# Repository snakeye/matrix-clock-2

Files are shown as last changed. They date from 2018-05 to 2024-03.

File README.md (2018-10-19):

# LED Matrix Clock

These clock are build using ESP8266 module ESP-12. Arduino IDE was used for the firmware development and upload.

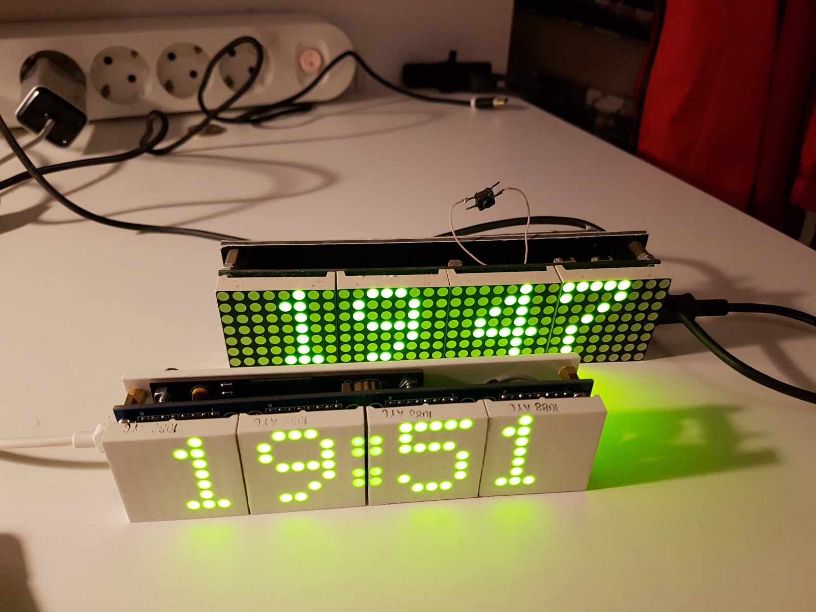
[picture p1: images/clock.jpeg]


## Features

* Built on ESP8266 WiFi module
* Time updates via NTP protocol
* Automatic time zone support
* Timekeeping without Internet connection (DS3231 chip)
* Brightness auto adjust

## Dependencies

* WiFi Manager - [https://github.com/tzapu/WiFiManager](https://github.com/tzapu/WiFiManager)
* Time library - [https://github.com/PaulStoffregen/Time](https://github.com/PaulStoffregen/Time)
* Time zone library - [https://github.com/JChristensen/Timezone](https://github.com/JChristensen/Timezone)
* NTP Client - [https://github.com/gmag11/NtpClient](https://github.com/gmag11/NtpClient)
* RTC library - [https://github.com/Makuna/Rtc](https://github.com/Makuna/Rtc)
* MAX7219 library - [https://github.com/snakeye/MAX7219_Display](https://github.com/snakeye/MAX7219_Display)

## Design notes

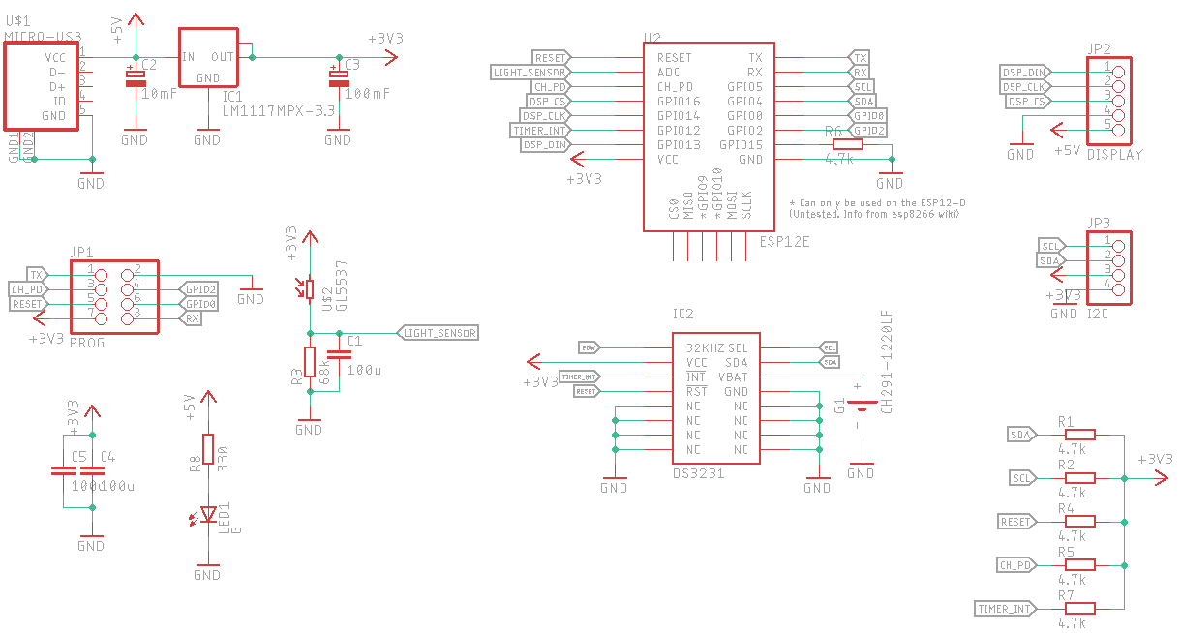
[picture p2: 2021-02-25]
images/schematics v1.png

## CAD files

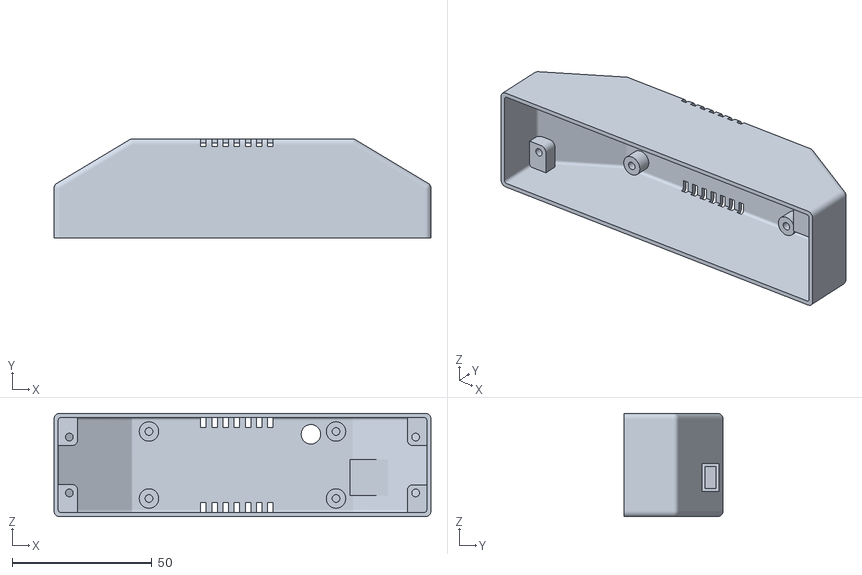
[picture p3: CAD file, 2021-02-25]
hardware/Enclosure.stl
135.0 x 35.5 x 37.0

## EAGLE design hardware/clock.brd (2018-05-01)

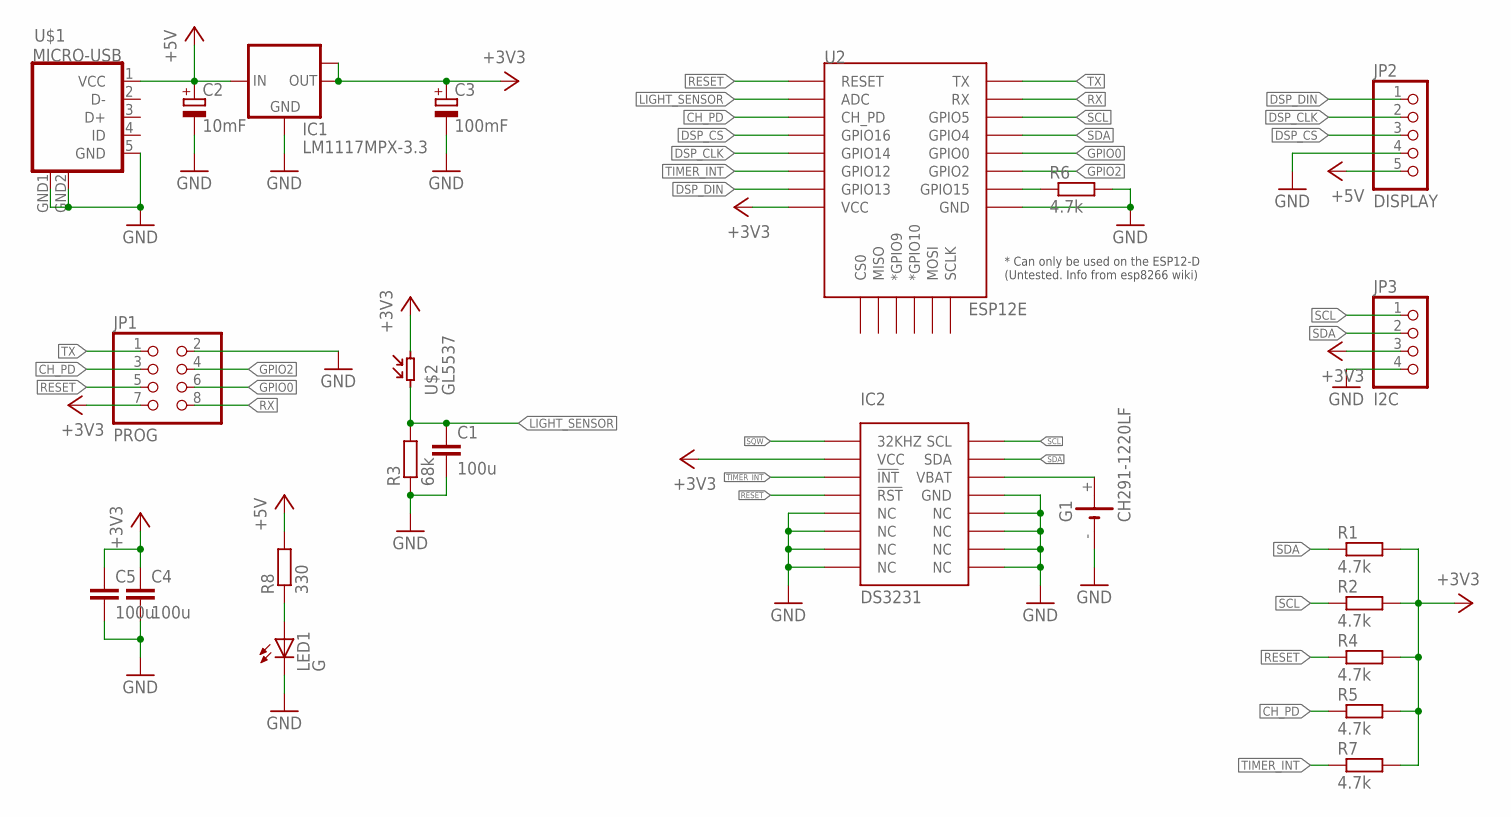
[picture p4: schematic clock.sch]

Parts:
C1, C4, C5: 100u; C0805
C2: 10mF; A/3216-18W
C3: 100mF; A/3216-18W
G1: CH291-1220LF
IC1: LM1117MPX-3.3; SOT223
IC2: DS3231; SOIC-16W
JP1: PROG; 2X04
JP2: DISPLAY; 1X05
JP3: I2C; 1X04
LED1: G; CHIPLED_0805
R1, R2, R4, R5, R6, R7: 4.7k; M0805
R3: 68k; M0805
R8: 330; M0805
U2: ESP12E; ESP12E-SMD
U$1: MICRO-USB
U$2: GL5537; GL55

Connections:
+3V3: C3.+, C4.1, C5.1, IC1.2 (OUT), IC1.TAB (OUT1), IC2.2 (VCC), JP1.7, JP3.3, R1.2, R2.2, R4.2, R5.2, R7.2, U2.VCC, U$2.P$2
+5V: C2.+, IC1.3 (IN), JP2.5, R8.2, U$1.1 (VCC)
CH_PD: JP1.3, R5.1, U2.CH_PD
DSP_CLK: JP2.2, U2.GPIO14
DSP_CS: JP2.3, U2.GPIO16
DSP_DIN: JP2.1, U2.GPIO13
GND: C1.2, C2.-, C3.-, C4.2, C5.2, G1.-, IC1.1 (GND), IC2.5 (NC), IC2.6 (NC), IC2.7 (NC), IC2.8 (NC), IC2.9 (NC), IC2.10 (NC), IC2.11 (NC), IC2.12 (NC), IC2.13 (GND), JP1.2, JP2.4, JP3.4, LED1.C, R3.1, R6.2, U2.GND, U$1.5 (GND), U$1.GND1 (GND), U$1.GND2 (GND)
GPIO0: JP1.6, U2.GPIO0
GPIO2: JP1.4, U2.GPIO2
GPIO15: R6.1, U2.GPIO15
LIGHT_SENSOR: C1.1, R3.2, U2.ADC, U$2.P$1
unnamed: LED1.A, R8.1
unnamed: G1.+, IC2.14 (VBAT)
RESET: IC2.4 (!RST), JP1.5, R4.1, U2.RESET
RX: JP1.8, U2.RXD0 (RX)
SCL: IC2.16 (SCL), JP3.1, R2.1, U2.GPIO5
SDA: IC2.15 (SDA), JP3.2, R1.1, U2.GPIO4
SQW: IC2.1 (32KHZ)
TIMER_INT: IC2.3 (!INT), R7.1, U2.GPIO12
TX: JP1.1, U2.TXD0 (TX)

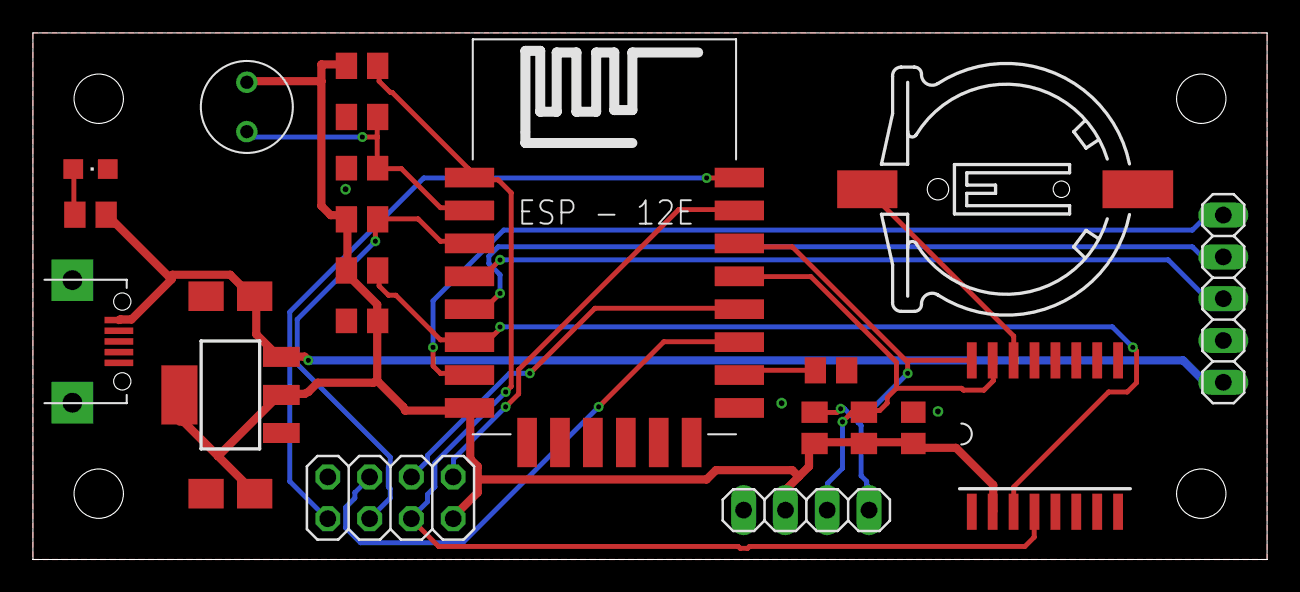
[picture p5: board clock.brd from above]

Board: 2 copper layers, 75.0 x 32.0 mm, 23 parts (0 on the bottom side), 19 nets.

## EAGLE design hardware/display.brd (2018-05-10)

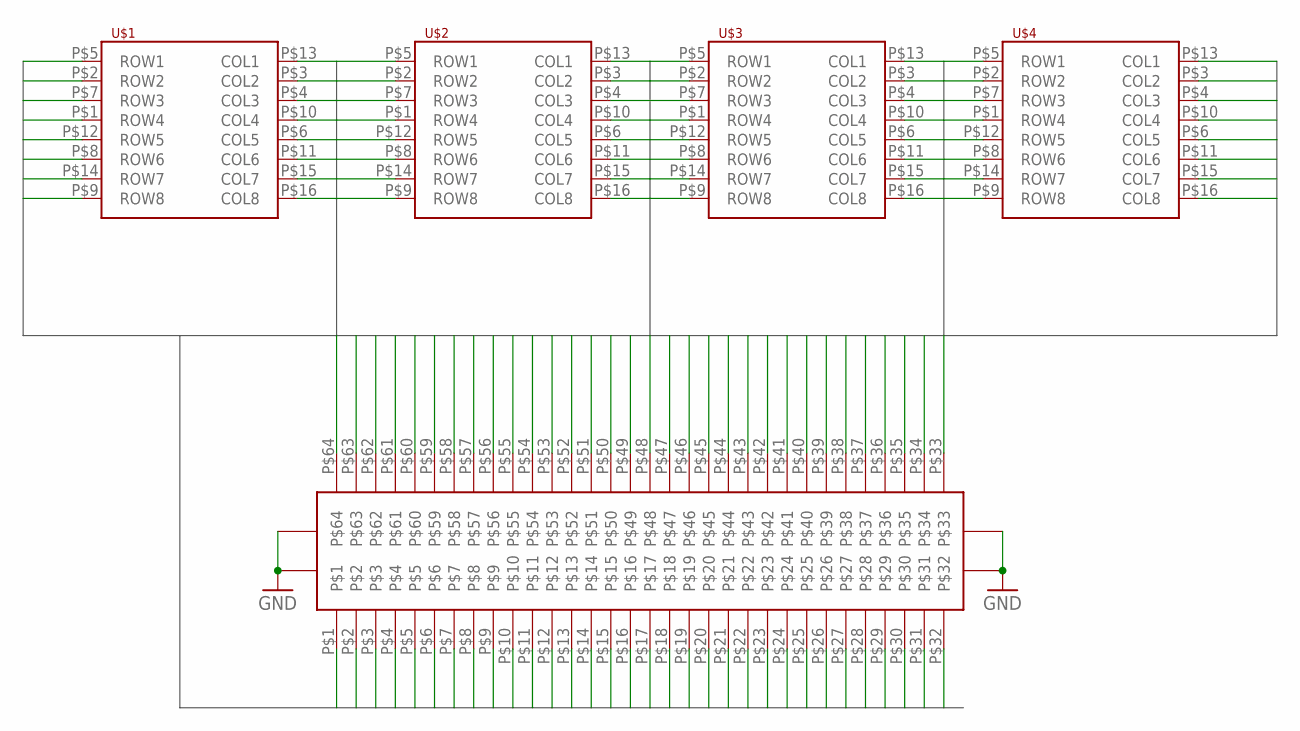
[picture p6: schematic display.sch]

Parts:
U$1, U$2, U$3, U$4: LED_8X8_MATRIX07088BH; MATRIX_8X8_20MM
U$5: ANGLE_BOARD_CONNECTORONE_SIDED; ONE_SIDED

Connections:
GND: U$5.GND@1 (GND), U$5.GND@2 (GND), U$5.GND@3 (GND), U$5.GND@4 (GND)
M1C1: U$1.P$13 (COL1), U$5.P$64
M1C2: U$1.P$3 (COL2), U$5.P$63
M1C3: U$1.P$4 (COL3), U$5.P$62
M1C4: U$1.P$10 (COL4), U$5.P$61
M1C5: U$1.P$6 (COL5), U$5.P$60
M1C6: U$1.P$11 (COL6), U$5.P$59
M1C7: U$1.P$15 (COL7), U$5.P$58
M1C8: U$1.P$16 (COL8), U$5.P$57
M1R1: U$1.P$5 (ROW1), U$5.P$1
M1R2: U$1.P$2 (ROW2), U$5.P$2
M1R3: U$1.P$7 (ROW3), U$5.P$3
M1R4: U$1.P$1 (ROW4), U$5.P$4
M1R5: U$1.P$12 (ROW5), U$5.P$5
M1R6: U$1.P$8 (ROW6), U$5.P$6
M1R7: U$1.P$14 (ROW7), U$5.P$7
M1R8: U$1.P$9 (ROW8), U$5.P$8
M2C1: U$2.P$13 (COL1), U$5.P$56
M2C2: U$2.P$3 (COL2), U$5.P$55
M2C3: U$2.P$4 (COL3), U$5.P$54
M2C4: U$2.P$10 (COL4), U$5.P$53
M2C5: U$2.P$6 (COL5), U$5.P$52
M2C6: U$2.P$11 (COL6), U$5.P$51
M2C7: U$2.P$15 (COL7), U$5.P$50
M2C8: U$2.P$16 (COL8), U$5.P$49
M2R1: U$2.P$5 (ROW1), U$5.P$9
M2R2: U$2.P$2 (ROW2), U$5.P$10
M2R3: U$2.P$7 (ROW3), U$5.P$11
M2R4: U$2.P$1 (ROW4), U$5.P$12
M2R5: U$2.P$12 (ROW5), U$5.P$13
M2R6: U$2.P$8 (ROW6), U$5.P$14
M2R7: U$2.P$14 (ROW7), U$5.P$15
M2R8: U$2.P$9 (ROW8), U$5.P$16
M3C1: U$3.P$13 (COL1), U$5.P$48
M3C2: U$3.P$3 (COL2), U$5.P$47
M3C3: U$3.P$4 (COL3), U$5.P$46
M3C4: U$3.P$10 (COL4), U$5.P$45
M3C5: U$3.P$6 (COL5), U$5.P$44
M3C6: U$3.P$11 (COL6), U$5.P$43
M3C7: U$3.P$15 (COL7), U$5.P$42
M3C8: U$3.P$16 (COL8), U$5.P$41
M3R1: U$3.P$5 (ROW1), U$5.P$17
M3R2: U$3.P$2 (ROW2), U$5.P$18
M3R3: U$3.P$7 (ROW3), U$5.P$19
M3R4: U$3.P$1 (ROW4), U$5.P$20
M3R5: U$3.P$12 (ROW5), U$5.P$21
M3R6: U$3.P$8 (ROW6), U$5.P$22
M3R7: U$3.P$14 (ROW7), U$5.P$23
M3R8: U$3.P$9 (ROW8), U$5.P$24
M4C1: U$4.P$13 (COL1), U$5.P$40
M4C2: U$4.P$3 (COL2), U$5.P$39
M4C3: U$4.P$4 (COL3), U$5.P$38
M4C4: U$4.P$10 (COL4), U$5.P$37
M4C5: U$4.P$6 (COL5), U$5.P$36
M4C6: U$4.P$11 (COL6), U$5.P$35
M4C7: U$4.P$15 (COL7), U$5.P$34
M4C8: U$4.P$16 (COL8), U$5.P$33
M4R1: U$4.P$5 (ROW1), U$5.P$25
M4R2: U$4.P$2 (ROW2), U$5.P$26
M4R3: U$4.P$7 (ROW3), U$5.P$27
M4R4: U$4.P$1 (ROW4), U$5.P$28
M4R5: U$4.P$12 (ROW5), U$5.P$29
M4R6: U$4.P$8 (ROW6), U$5.P$30
M4R7: U$4.P$14 (ROW7), U$5.P$31
M4R8: U$4.P$9 (ROW8), U$5.P$32

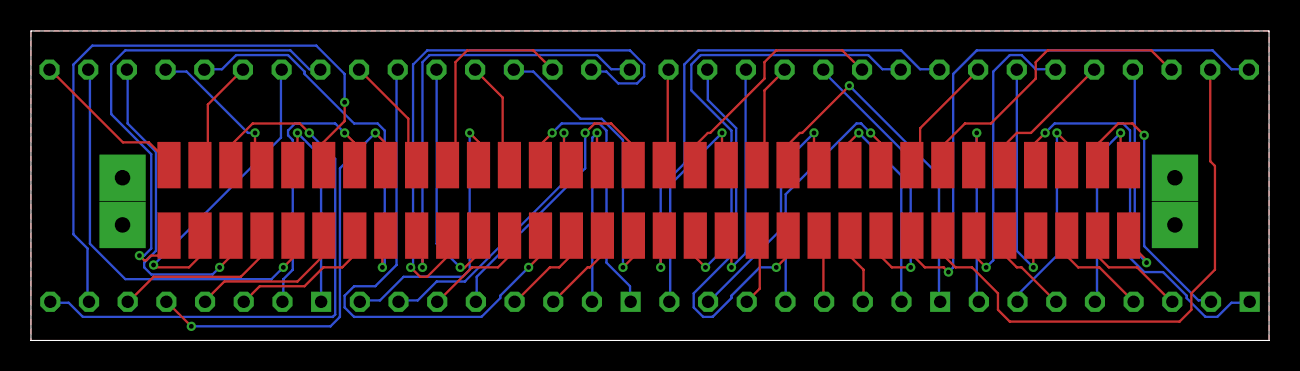
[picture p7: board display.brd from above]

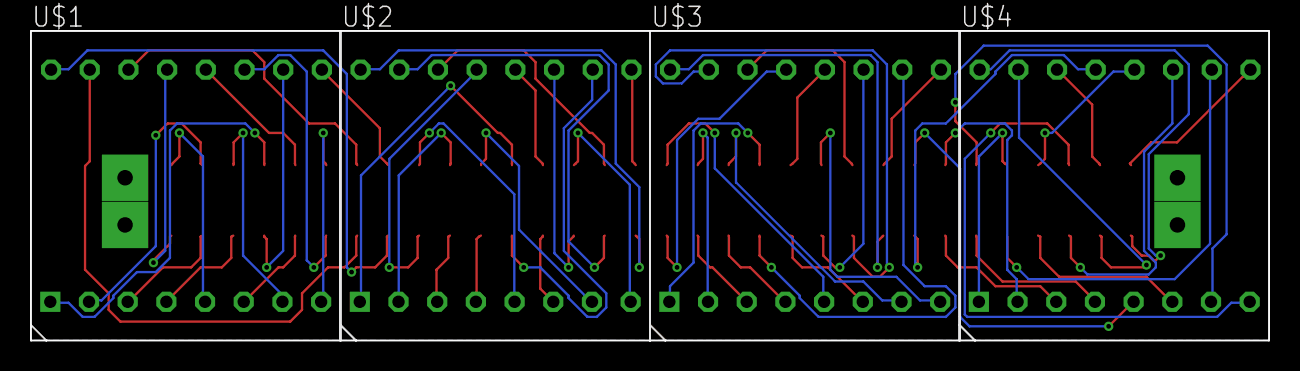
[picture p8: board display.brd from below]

Board: 2 copper layers, 80.0 x 20.0 mm, 5 parts (4 on the bottom side), 65 nets.

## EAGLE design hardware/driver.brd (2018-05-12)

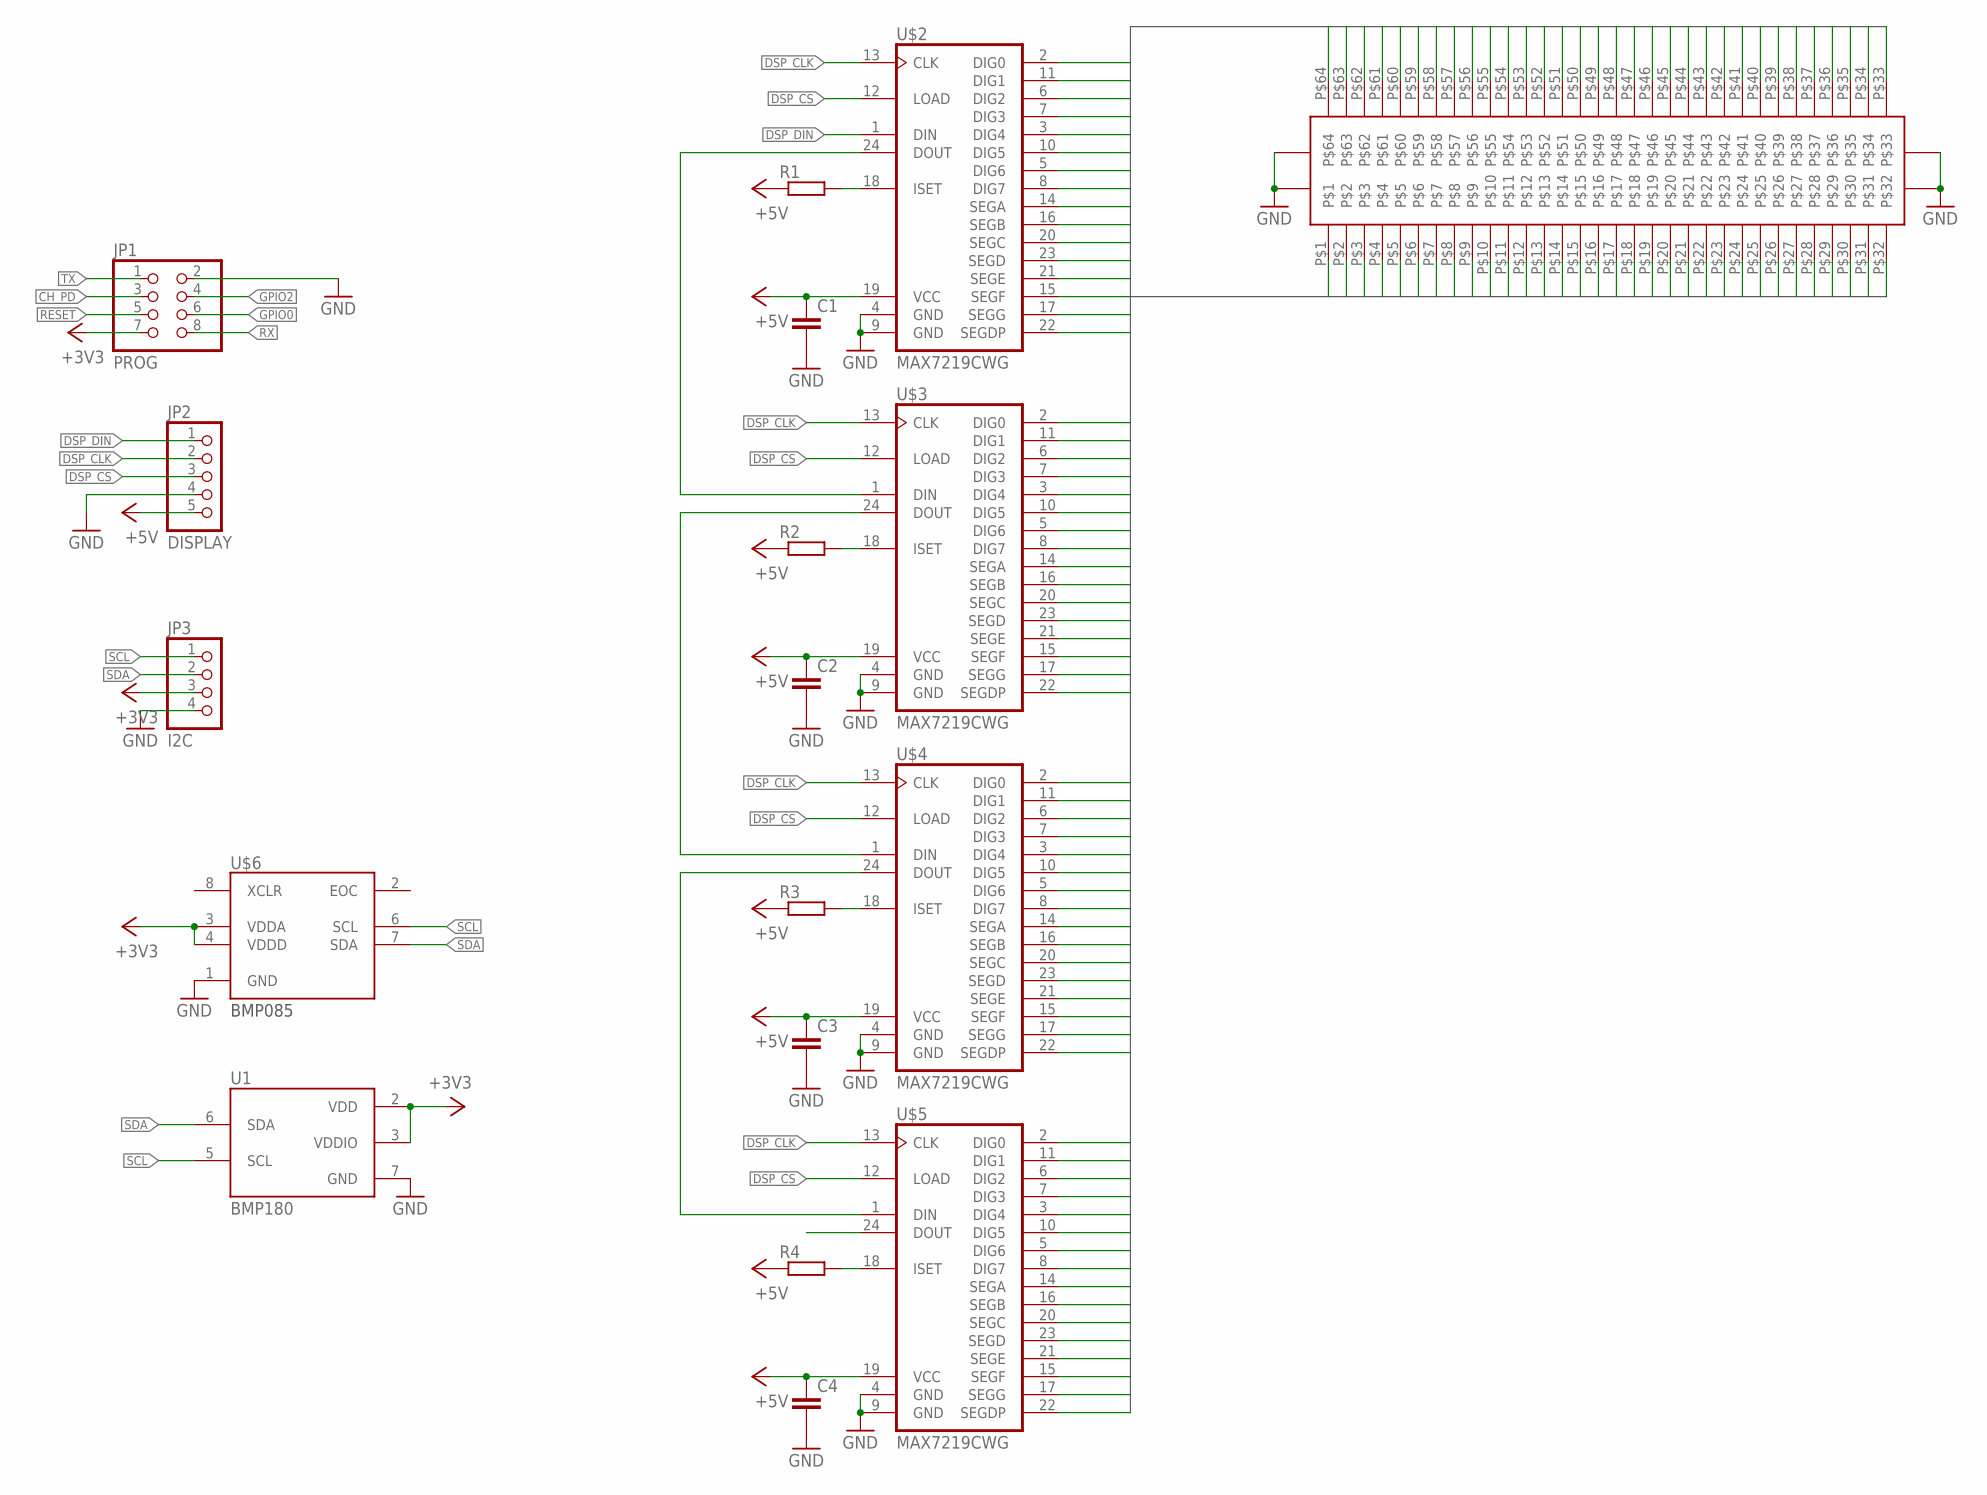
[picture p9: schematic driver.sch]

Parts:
C1, C2, C3, C4: C-EUC0805; C0805
JP1: PROG; 2X04
JP2: DISPLAY; 1X05
JP3: I2C; 1X04
R1, R2, R3, R4: R-EU_R0805; R0805
U1: BMP180
U$1: ANGLE_BOARD_CONNECTORTWO_SIDED; TWO_SIDED
U$2, U$3, U$4, U$5: MAX7219CWG; SO24L
U$6: BMP085

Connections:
+3V3: JP1.7, JP3.3, U1.2 (VDD), U1.3 (VDDIO), U$6.3 (VDDA), U$6.4 (VDDD)
+5V: C1.1, C2.1, C3.1, C4.1, JP2.5, R1.1, R2.1, R3.1, R4.1, U$2.19 (VCC), U$3.19 (VCC), U$4.19 (VCC), U$5.19 (VCC)
CH_PD: JP1.3
DSP_CLK: JP2.2, U$2.13 (CLK), U$3.13 (CLK), U$4.13 (CLK), U$5.13 (CLK)
DSP_CS: JP2.3, U$2.12 (LOAD), U$3.12 (LOAD), U$4.12 (LOAD), U$5.12 (LOAD)
DSP_DIN: JP2.1, U$2.1 (DIN)
GND: C1.2, C2.2, C3.2, C4.2, JP1.2, JP2.4, JP3.4, U1.7 (GND), U$1.GND@1 (GND), U$1.GND@2 (GND), U$1.GND@3 (GND), U$1.GND@4 (GND), U$2.4 (GND), U$2.9 (GND), U$3.4 (GND), U$3.9 (GND), U$4.4 (GND), U$4.9 (GND), U$5.4 (GND), U$5.9 (GND), U$6.1 (GND)
GPIO0: JP1.6
GPIO2: JP1.4
M1C1: U$1.P$64, U$2.2 (DIG0)
M1C2: U$1.P$63, U$2.11 (DIG1)
M1C3: U$1.P$62, U$2.6 (DIG2)
M1C4: U$1.P$61, U$2.7 (DIG3)
M1C5: U$1.P$60, U$2.3 (DIG4)
M1C6: U$1.P$59, U$2.10 (DIG5)
M1C7: U$1.P$58, U$2.5 (DIG6)
M1C8: U$1.P$57, U$2.8 (DIG7)
M1R1: U$1.P$1, U$2.14 (SEGA)
M1R2: U$1.P$2, U$2.16 (SEGB)
M1R3: U$1.P$3, U$2.20 (SEGC)
M1R4: U$1.P$4, U$2.23 (SEGD)
M1R5: U$1.P$5, U$2.21 (SEGE)
M1R6: U$1.P$6, U$2.15 (SEGF)
M1R7: U$1.P$7, U$2.17 (SEGG)
M1R8: U$1.P$8, U$2.22 (SEGDP)
M2C1: U$1.P$56, U$3.2 (DIG0)
M2C2: U$1.P$55, U$3.11 (DIG1)
M2C3: U$1.P$54, U$3.6 (DIG2)
M2C4: U$1.P$53, U$3.7 (DIG3)
M2C5: U$1.P$52, U$3.3 (DIG4)
M2C6: U$1.P$51, U$3.10 (DIG5)
M2C7: U$1.P$50, U$3.5 (DIG6)
M2C8: U$1.P$49, U$3.8 (DIG7)
M2R1: U$1.P$9, U$3.14 (SEGA)
M2R2: U$1.P$10, U$3.16 (SEGB)
M2R3: U$1.P$11, U$3.20 (SEGC)
M2R4: U$1.P$12, U$3.23 (SEGD)
M2R5: U$1.P$13, U$3.21 (SEGE)
M2R6: U$1.P$14, U$3.15 (SEGF)
M2R7: U$1.P$15, U$3.17 (SEGG)
M2R8: U$1.P$16, U$3.22 (SEGDP)
M3C1: U$1.P$48, U$4.2 (DIG0)
M3C2: U$1.P$47, U$4.11 (DIG1)
M3C3: U$1.P$46, U$4.6 (DIG2)
M3C4: U$1.P$45, U$4.7 (DIG3)
M3C5: U$1.P$44, U$4.3 (DIG4)
M3C6: U$1.P$43, U$4.10 (DIG5)
M3C7: U$1.P$42, U$4.5 (DIG6)
M3C8: U$1.P$41, U$4.8 (DIG7)
M3R1: U$1.P$17, U$4.14 (SEGA)
M3R2: U$1.P$18, U$4.16 (SEGB)
M3R3: U$1.P$19, U$4.20 (SEGC)
M3R4: U$1.P$20, U$4.23 (SEGD)
M3R5: U$1.P$21, U$4.21 (SEGE)
M3R6: U$1.P$22, U$4.15 (SEGF)
M3R7: U$1.P$23, U$4.17 (SEGG)
M3R8: U$1.P$24, U$4.22 (SEGDP)
M4C1: U$1.P$40, U$5.2 (DIG0)
M4C2: U$1.P$39, U$5.11 (DIG1)
M4C3: U$1.P$38, U$5.6 (DIG2)
M4C4: U$1.P$37, U$5.7 (DIG3)
M4C5: U$1.P$36, U$5.3 (DIG4)
M4C6: U$1.P$35, U$5.10 (DIG5)
M4C7: U$1.P$34, U$5.5 (DIG6)
M4C8: U$1.P$33, U$5.8 (DIG7)
M4R1: U$1.P$25, U$5.14 (SEGA)
M4R2: U$1.P$26, U$5.16 (SEGB)
M4R3: U$1.P$27, U$5.20 (SEGC)
M4R4: U$1.P$28, U$5.23 (SEGD)
M4R5: U$1.P$29, U$5.21 (SEGE)
M4R6: U$1.P$30, U$5.15 (SEGF)
M4R7: U$1.P$31, U$5.17 (SEGG)
M4R8: U$1.P$32, U$5.22 (SEGDP)
unnamed: R1.2, U$2.18 (ISET)
unnamed: U$2.24 (DOUT), U$3.1 (DIN)
unnamed: R2.2, U$3.18 (ISET)
unnamed: U$3.24 (DOUT), U$4.1 (DIN)
unnamed: R3.2, U$4.18 (ISET)
unnamed: U$4.24 (DOUT), U$5.1 (DIN)
unnamed: R4.2, U$5.18 (ISET)
RESET: JP1.5
RX: JP1.8
SCL: JP3.1, U1.5 (SCL), U$6.6 (SCL)
SDA: JP3.2, U1.6 (SDA), U$6.7 (SDA)
TX: JP1.1

Board: 2 copper layers, 18 parts (8 on the bottom side), 79 nets, no tracks yet.

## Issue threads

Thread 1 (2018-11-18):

Definition of Pins

Dancopy, 2018-11-18:
Sorry if I'm wrong friend but, I have not seen and I do not know what is the definition of the pins of the Matrix and the DS3231 to the ESP8266; And here, the ESP connects to WiFi over IP? Because I did not see SSID and no password! Thanks for the code

snakeye, 2018-11-19:
LED matrix uses MAX7219 chip and therefore requires five wires to connect - Ground, +5V, DIN, CLK, CS. DS3231 is connected by I2C bus and therefore requires two wires - SDA and SCL. The pins are marked on the schematic
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

WiFi connection is configured by the WiFi manager library, please refer the documentation - https://github.com/tzapu/WiFiManager

Dancopy, 2018-11-19:
Is that I thought that the pins of MAX7219 and DS3231 should be declared in the sketch but, I saw that only the CS pin is declared here: const int pinDisplayCS = 16. Do the other pins (DIN and CLK) need not be declared? Thank you++

snakeye, 2018-11-20:
Ah, now I see.

For MAX7219 the only manual definition is CS pin. Two others are defined in SPI.h, their connections are DIN - GPIO13 (HSPID) and CLK - GPIO14 (HSPICLK).

For DS3231 connection refer to the RTC library documentation - https://github.com/Makuna/Rtc/wiki#connecting-the-devices

Dancopy, 2018-11-20:
OK! Thank you very much

Dancopy, 2018-11-27:
Hi Andrey! What paper or film did you use to spread the displays? It was beautiful! Thank you
________________________________
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

snakeye, 2018-11-28:
It's some white semi-transparent film I have for years. I don't remember where it was taken from.

Closed 2018-11-20.

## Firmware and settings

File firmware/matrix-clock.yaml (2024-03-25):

esphome:
  name: matrix-clock
  platform: ESP8266
  board: esp12e
  platformio_options:
    upload_speed: 921600
  includes:
    - ambient_light_sensor.h

wifi:
  ssid: !secret wifi_ssid
  password: !secret wifi_password

  # Enable fallback hotspot (captive portal) in case wifi connection fails
  ap:
    ssid: "Matrix-Clock Fallback Hotspot"
    password: "dcgcN2Ao6Ilo"

# Enable logging
logger:

# Enable OTA Firmware upload
ota:

spi:
  clk_pin: GPIO14
  mosi_pin: GPIO13

i2c:
  sda: GPIO4
  scl: GPIO5

time:
  - platform: sntp
    id: sntp_time
    timezone: Europe/Berlin
    on_time_sync:
      then:
        ds1307.write_time:

  - platform: ds1307
    id: rtc_time
    timezone: Europe/Berlin

sensor:
  - platform: custom
    lambda: |-
      auto ambient_light_sensor = new AmbientLightSensor();
      App.register_component(ambient_light_sensor);
      return {ambient_light_sensor};
    sensors:
      id: ambient_light
      name: "Ambient Light Sensor"

display:
  - platform: max7219digit
    cs_pin: GPIO16
    num_chips: 4
    lambda: |-
      auto now = id(rtc_time).now();

      if(now.is_valid()) {
        it.printf(16, -1, id(digit_font), TextAlign::TOP_CENTER, "%d:%02d", now.hour, now.minute);
      }
      else {
        it.print(16, -1, id(digit_font), TextAlign::TOP_CENTER, "--:--");
      }

      it.intensity(id(ambient_light).state);

font:
  - file: "fonts/pixelmix.ttf"
    id: digit_font
    size: 8
    glyphs: ["0", "1", "2", "3", "4", "5", "6", "7", "8", "9", ":", "-"]

status_led:
  pin:
    number: GPIO2
    inverted: True

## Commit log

2018-04-26 initial schematic files
    [clock.brd, clock.sch]
2018-04-29 First version of board design
    [clock.brd, clock.sch]
2018-04-29 schematic image
2018-04-29 board updated
    [clock.brd, clock.sch]
2018-05-01 final design
    [clock.GBL, clock.GBO, clock.GBP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]
2018-05-10 display and driver boards
    [display.brd, display.sch, driver.brd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]
2018-05-12 max7219 connection
    [driver.brd, driver.sch]
2018-05-31 added sources for arduino
2018-09-30 added arduino dir
2018-10-01 Added .gitignore for arduino project
2018-10-03 connected led matrix display
2018-10-03 Onboard led on when no wifi connection
2018-10-12 Set initial brightness; disable led
2021-02-25 ESPHome version
    [Enclosure.stl, clock.brd, clock.sch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]
